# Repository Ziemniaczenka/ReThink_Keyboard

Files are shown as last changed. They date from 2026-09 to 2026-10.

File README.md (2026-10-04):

# ReThink Keyboard

Adapting older ThinkPad laptop keyboard modules into standalone keyboards using Framework Control Board.

## Hardware overview
- **Framework Control Board** - nRF54LM20A, Bluetooth/dongle/USB-C connection, nPM1300 power management IC.
- **ReThink Adapter Board** - bridge between Control Board and ThinkPad keyboards.
- **3D Printed case** - housing for components, different for each keyboard type.
- **ThinkPad keyboard modules** - 6 and 7row, classic and chiclet, with or without backlight, with integrated Pointing Stick (nub) and mouse keys. Full list TBD.
- **ZMK Firmware** - based on Zephyr RTOS, provides customizability. Each keyboard type will be different shield.

> Note: This is preliminary information. Everything is subject to change and more information will follow.

## Reference pinouts

- [Framework Control Board FFC connectors](docs/pinouts/framework_ffc.md)
- [Mezzanine Connector (e.g. T60/T420)](docs/pinouts/mezzanine.md)
- [FFC1 (e.g. L420)](docs/pinouts/ffc1.md)
- [FFC2 (e.g. T480/T580/L14)](docs/pinouts/ffc2.md)

## Mechanical CAD
  
- TBD

## ReThink Adapter

   Adapter board connects to Control Board using FFC cables, has a bunch of connectors for different generations of ThinkPad keyboard, boost converters (for pointing stick, backlight) and I2C IO expander (required to keep all keyboard buttons and diodes functional).

   - [Schematic (WiP)](circuit/ReThink_adapter.pdf)
   - [BOM (WiP)](circuit/ReThink_adapter/ReThink_adapter.csv)

## Battery

- Picoblade 3-pin with NTC thermistor.
- TBD

## Firmware and Bootloader

- ZMK Configuration will be based on GitHub in separate repository (TBD)

## Compatibility Table

- TBD

## License

ReThink keyboard by Ziemniaczenka is licensed under CC BY-SA 4.0.
To view a copy of this license, visit https://creativecommons.org/licenses/by-sa/4.0/

Component 3D models located under `circuit/libraries/3dmodels/` are the intellectual property of their respective manufacturers and are provided for reference/visualization purposes only. They are not covered by the above license; all rights remain with their original owners.

## Disclaimers
> Framework Control Board was provided pre-release by Framework Computer Inc. through Control Board Developer Program.

> ThinkPad and TrackPoint are registered trademarks of Lenovo. ReThink is an independent open-source project and is not affiliated with, endorsed by, or certified by Lenovo Group Limited.

## References
1. https://github.com/FrameworkComputer/Framework-Wireless-Touchpad-Keyboard
2. https://github.com/badjeff/kb_zmk_ps2_mouse_trackpoint_driver
3. https://github.com/rampadc/zmk-thinkpad
4. https://github.com/delingren/thinkpad_keyboards

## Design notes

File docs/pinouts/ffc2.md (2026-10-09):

# FFC 2 connector

Modern 6-row keyboard\
Dual keyed FFC connectors:
- 36-pin (40-pin with numpad) P0.5mm keyed for Matrix, LEDs, Navigation Buttons
- 12-pin P1.0mm keyed for Pointing Stick and Backlight

## Compatible connectors

1. 36-pin
   - pitch: 0.5mm
   - key: **notched**
   - side: bottom
   - lock: yes?
   - Compatible MPN:
     - HIGHS_FC5AF361-1151H (T470)
     - Hirose FH34SRJ-40S-0.5SH(50) (**40pin, straight key. Skip 2 pins from each end!**)
       - [Mouser](https://www.mouser.pl/en/ProductDetail/Hirose-Connector/FH34SRJ-40S-0.5SH50?qs=iyLo5FA4poDa6AcLdJDWMw%3D%3D)
2. 40-pin
   - pitch: 0.5mm
   - key: **tabbed**
   - side: bottom
   - lock: yes?
   - Compatible MPN:
     - JAE-CON40-7-GP (T570)
     - HIGHS_FC5AF401-3181H (L14g1, L15g1, E480, E580)
     - Hirose FH52-40S-0.5SH (**direct match**)
       - [Mouser](https://www.mouser.pl/en/ProductDetail/Hirose-Connector/FH52-40S-0.5SH?qs=x%2FqqGkZFGGusKc6kcNGZEQ%3D%3D)
3. 12-pin
   - pitch: 1.0mm
   - key: **notched**
   - side: bottom
   - lock: yes?
   - Compatible MPN:
     - HIGHS_FC1AF121-1151H (T480, L14G1)
     - JAE-CON12-1-GP-U (T580)
     - JAE_FL10F012HA1R3000 (E490)
     - Omron XF3M(1)-1415-1B (**14pin, straight key. Skip 1 pin from each end, needs aligment guide! (cable width: 14mm, 14pin socket opening width: 15mm**)
       - [Mouser](https://www.mouser.pl/en/ProductDetail/Omron-Electronics/XF3M1-1415-1B?qs=0q6jlcGHEi2cMtnOEJgNDA%3D%3D)

## Compatible models (TBD)

- T470, T480, T25 (w/o power button), A475, A485 **(12pin left, 36pin right, kb right side) Mounting hole coliding with adapter board, fix!!!**
- ~~A285, L13g1, L13g2?, X280, X290, X390, X395, X13g1? **(36pin left, 12pin right, kb left side)**~~
- T570, T580, P51s, P52s (40pin left, 12pin right, kb **right** side) **(possible collision?)**
- L14g1, L14g2 (40pin left, 12pin right, kb left side) **Mounting hole coliding with adapter board, fix!!!**
- L15g1, L15g2 (40pin left, 12pin right, kb left side) **(possible collision?)**
- E480, E485, E490, E495, L380, L390, L480, L490, T480s, T490, T14g1, T14g2, P43, P43s, P14sG1, P14sG2 (40pin left, 12pin right, kb left side)
- E580, E585, E590, E595, L580, L590, T590, P52, P53, P53s, P72, P73 (40pin left, 12pin right, kb left side)
- T15g1, T15g2, P15sG1, P15sG2 (40pin left, 12pin right, kb left side)
- P15g1, P15g2, P17g1, P17g2 (40pin left, 12pin right, kb **right** side)

## Pinout (36-pin/40pin)

|  Pin  | T480 | T580/L14 | Type | Adapter Board |
| :---: | :---: | :---: | :---: | :---: |
| 1 | SENSE3 | SENSE3 | | |
| 2 | SENSE7 | SENSE7 | | |
| 3 | SENSE6 | SENSE6 | | |
| 4 | DRV14 | DRV14 | | |
| 5 | SENSE4 | SENSE4 | | |
| 6 | SENSE1 | SENSE1 | | |
| 7 | DRV0 | DRV0 | | |
| 8 | SENSE2 | SENSE2 | | |
| 9 | SENSE0 | SENSE0 | | |
|  10 | DRV4 | DRV4 | | |
|  11 | DRV2 | DRV2 | | |
|  12 | SENSE5 | SENSE5 | | |
|  13 | DRV1 | DRV1 | | |
|  14 | DRV3 | DRV3 | | |
|  15 | DRV6 | DRV6 | | |
|  16 | DRV7 | DRV7 | | |
|  17 | DRV5 | DRV5 | | |
|  18 | DRV15 | DRV15 | | |
|  19 | DRV13 | DRV13 | | |
|  20 | DRV9 | DRV9 | | |
|  21 | DRV12 | DRV12 | | |
|  22 | DRV10 | DRV10 | | |
|  23 | DRV8 | DRV8 | | |
|  24 | DRV11 | DRV11 | | |
|  25 | VCC3M | VCC3M | 0.1u to GND | |
|  26 |  LED_FNLOCK  |  LED_FNLOCK  | 100R series resistor, 0.1u to GND | |
|  27 | LED_MUTE | LED_MUTE | 100R series resistor, 0.1u to GND | |
|  28 | LED_MICMUTE  | LED_MICMUTE  | 100R series resistor, 0.1u to GND | |
|  29 | HOTKEY | HOTKEY | | |
|  30 | GND | GND | | GND |
|  31 | LED_CAPSLOCK | LED_CAPSLOCK | 100R series resistor, 0.1u to GND | |
|  32 | GND | GND | | GND |
|  33 | TP4LEFT | TP4LEFT | | |
|  34 | TP4RIGHT | TP4RIGHT | | |
|  35 |  TP4MIDDLE |  TP4MIDDLE | | |
|  36 |  **KBD_ID**  |  **DRV16** | KBD_ID NC on 01AX516, <br/> NC on non-numpad L14 etc. | |
|  37 | - | DRV17 | NC on non-numpad L14 etc. | |
|  38 | - | LED_NUMLOCK  | NC on non-numpad L14 etc, 100R series resistor | |
|  39 | - | NC | Not Connected | |
|  40 | - | NC | Not Connected | |

## Pinout (12-pin)

|  Pin  | T480 | T580 | L14 | Type | Adapter Board |
| :---: | :---: | :---: | :---: | :---: | :---: |
| **1** |  **VCC5B**  |  **VCC5B**  |  **VCC3B**  | VCC_TP, 10nF to GND  <br/> option of 3V3 and 5V, diff defaults | |
| 2 | TP4DATA | TP4DATA | TP4DATA | Pointing Stick Data, Pullup 4.7k@VCC_TP | |
| 3 |  TP4_RESET  |  TP4_RESET  |  TP4_RESET  | Pointing Stick reset, Pullup 10k@VCC_TP | |
| 4 |  TP4MIDDLE  |  TP4MIDDLE  |  TP4MIDDLE  | | |
| 5 |  TP4RIGHT |  TP4RIGHT |  TP4RIGHT | | |
| 6 | TP4LEFT | TP4LEFT | TP4LEFT | | |
| 7 | GND | GND | GND | Pointing Stick GND | |
| 8 | TP4CLK | TP4CLK | TP4CLK | Pointing Stick Clk, 4.7k@VCC_TP | |
| 9 | VCC5B | VCC5B | VCC5B | LED VCC (5V), 2x22uF to GND | |
|  10 | KBD_BL_PWM  | KBD_BL_PWM  | KBD_BL_PWM  | LED PWM, 220p to GND | |
|  11 | KBD_BL_DTCT | KBD_BL_DTCT | KBD_BL_DTCT | Backlight detection | |
|  12 | GND | GND | GND | LED GND | |

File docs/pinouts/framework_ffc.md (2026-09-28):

# Framework Control Board FFC connectors

34-pin FFC connector for data as well as 6-pin for Backlight power  

## Compatible connectors

1. 34-pin
   - pitch: 0.5mm
   - key: straight
   - side: dual?
   - lock: back
   - Compatible MPN:
     - Hirose FH34SRJ-34S-0.5SH(50)
       - [Mouser](https://www.mouser.pl/en/ProductDetail/Hirose-Connector/FH34SRJ-34S-0.5SH50?qs=iyLo5FA4poAumYnqXazWvw%3D%3D)
2. 6-pin
   - pitch: 0.5mm
   - key: straight
   - side: dual?
   - lock: back
   - Compatible MPN:
     - Hirose FH34SRJ-6S-0.5SH(50)
       - [Mouser](https://www.mouser.pl/en/ProductDetail/Hirose-Connector/FH34SRJ-6S-0.5SH50?qs=vnk2wBG9e15jF3vv7p0sbw%3D%3D)

## Pinout (34-pin)

| Pin (CB) |  nRF  | Control Board | Type | Adapter Board | Pin (AB) |
| :---: | :---: | :---: | :---: | :---: | :---: |
| 1 | P0.00 | KSI_00_IN | | IO0 | 34 |
| 2 | P0.01 | KSI1 | | IO1 | 33 |
| 3 | P0.02 | KSI2 | | IO2 | 32 |
| 4 | P0.03 | KSI_03_IN | | IO3 | 31 |
| 5 | P0.04 | KSI4 | | IO4 | 30 |
| 6 | P0.05 | KSI5 | | IO5 | 29 |
| 7 | P0.06 | KSI6 | | IO6 | 28 |
| 8 | P0.07 | KSI7 | | IO7 | 27 |
| 9 | P1.00 | KSO0 | | IO8 | 26 |
| 10 | P1.01 | KSO1 | | IO9 | 25 |
| 11 | P1.18 | KSO_02_IN | | IO10 | 24 |
| 12 | P1.19 | KSO3 | | IO11 | 23 |
| 13 | P1.04 | KSO4 | | IO12 | 22 |
| 14 | P1.05 | KSO5 | | IO13 | 21 |
| 15 | P1.06 | KSO6 | | IO14 | 20 |
| 16 | P1.07 | KSO7 | | IO15 | 19 |
| 17 | P1.08 | KSO8 | | IO16 | 18 |
| 18 | P1.09 | KSO9 | | IO17 | 17 |
| 19 | P1.10 | KSO10 | | IO18 | 16 |
| 20 | P1.11 | KSO11 | | IO19 | 15 |
| 21 | P1.12 | KSO12 | | IO20 | 14 |
| 22 | P1.13 | KSO13 | | IO21 | 13 |
| 23 | P1.14 | KSO14 | | IO22 | 12 |
| 24 | P1.15 | KSO15 | | IO23 | 11 |
| 25 | P1.16 | KSO16 | | IO24 | 10 |
| 26 | P1.17 | KSO17 | | IO25 | 9 |
| 27 | - | CAPS_P | VLED_3.3V (always on) | LED_3V3 | 8 |
| 28 | P3.07 | CAPS_N | to ground through 330R and CAP_LED MOSFET | CAPS_N | 7 |
| 29 | - | NC | Not Connected | NC | 6 |
| 30 | P3.08 |  TP_I2C_SDA | | I2C_SDA | 5 |
| 31 | P3.04 |  TP_I2C_CLK | | I2C_CLK | 4 |
| 32 | - |  TP_VDD_3.3V  | switchable by TP_Power_Control | TP_3V3 | 3 |
| 33 | P3.06 | TP_INT | | IO26 | 2 |
| 34 | - | TP_GND | To GND through R8 0R | GND | 1 |

## Pinout (6-pin)

| Pin (CB) | Control Board | Type | Adapter Board | Pin (AB) |
| :---: | :---: | :---: | :---: | :---: |
| 1 | VLED_BL | | VIN | 6 |
| 2 | VLED_BL | | VIN | 5 |
| 3 | NC | Not Connected | | 4 |
| 4 | NC | Not Connected | | 3 |
| 5 | GND | | GND | 2 |
| 6 | GND | | GND | 1 |

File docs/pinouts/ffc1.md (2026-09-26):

# FFC 1 connector

Classic 6-row keyboard
Dual FFC connectors (30-pin P1.0mm for matrix, 8-pin P1.0mm for Pointing Stick)

## Compatible connectors

1. 30-pin
   - pitch: 1.0mm
   - key: straight
   - side: **top** (based on planed bends for adapter placement, not on laptop placement)
   - lock: yes?
   - Compatible MPN:
     - 85208-3007N-01???
     - Omron XF3M(1)-3015-1B
       - [Mouser](https://www.mouser.pl/en/ProductDetail/Omron-Electronics/XF3M1-3015-1B?qs=1He0yLMpldDsC1Cgk53qLQ%3D%3D)
2. 8-pin
   - pitch: 1.0mm
   - key: straight
   - side: **bottom**
   - lock: yes?
   - Compatible MPN:
     - Omron XF3M(1)-0815-1B
       - [Mouser](https://www.mouser.pl/en/ProductDetail/Omron-Electronics/XF3M1-0815-1B?qs=q%2FTJjBi8OU92LX9jQs7B8Q%3D%3D)

## Compatible models (TBD)

- L410 L412 L420 L421 L510 L512 L520 SL300 SL410 SL510
- X120???

## Pinout (30-pin)

|  Pin  |  L420  | Type | Adapter Board |
| :---: | :----: | :---: | :---: |
| 1 | NC | Not Connected | |
| 2 | NC | Not Connected | |
| 3 | RIGHT  | Navigation Button | |
| 4 | MIDDLE | Navigation Button | |
| 5 |  LEFT  | Navigation Button | |
| 6 |  GND | | GND |
| 7 |  MY15  | | |
| 8 |  MY10  | | |
| 9 |  MY11  | | |
|  10 |  MY14  | | |
|  11 |  MY13  | | |
|  12 |  MY12  | | |
|  13 |  MY3 | | |
|  14 |  MY6 | | |
|  15 |  MY8 | | |
|  16 |  MY7 | | |
|  17 |  MY4 | | |
|  18 |  MY2 | | |
|  19 |  MX0 | | |
|  20 |  MY1 | | |
|  21 |  MY5 | | |
|  22 |  MX3 | | |
|  23 |  MX2 | | |
|  24 |  MY0 | | |
|  25 |  MX5 | | |
|  26 |  MX4 | | |
|  27 |  MY9 | | |
|  28 |  MX6 | | |
|  29 |  MX7 | | |
|  30 |  MX1 | | |

## Pinout (8-pin)
|  Pin  | L420 | Type  | Adapter Board |
| :---: | :---: | :---: | :---: |
| 1 |  TRACK_POINT_DAT  | | |
| 2 | TRACK_POINT_RESET | | |
| 3 | MIDDLE | | |
| 4 | RIGHT | | |
| 5 | LEFT | | |
| 6 |  TRACK_POINT_CLK  | | |
| 7 | GND | | |
| 8 | 5V | | |

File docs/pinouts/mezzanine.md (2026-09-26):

# Mezzanine connector

Classic 7-row keyboard (2 types) and old chiclet

## Compatible connectors
1. Mezzanine
   - pin count: 2x20pin 
   - pitch: 0.5mm
   - Compatible MPN:
     - JAE AA01B-S040VA1 (original, hard to find)
       - [Quest Components](https://www.questcomp.com/part/4/aa01b-s040va1-r3000/434153986)
     - Molex 543630489 (WM6787CT-ND) (alternative, no locating feature, easy to break and posibility of misaligment)
       - [TTI](https://www.tti.com/content/ttiinc/en/apps/part-detail.html?partsNumber=543630489,&mfgShortname=MOL)
       - [DigiKey](https://www.digikey.pl/en/products/detail/molex/0543630489/3044861)
     - maybe 4-5353512-0???

## Compatible models (TBD)
- T60, T61, T400, R60, R61, R400, R500, W500, W700 (w/o numpad)  (classic type 1, narrow navigation keys, gap between kb and navigation keys)
- X60?, X60S?, X61?, X61S? (gap filled between kb and navigation keys)
- X200?, X210?, X300? (colorful narrow navigation keys, gap filled between kb and navigation keys)
- T410, T420, T510, T520, W510, W520, X220 (classic type 2, wide navigation keys)
- T430, T530, W530, X230 (chiclet with top bezel, optional backlight)
## Pinout

Slight differences between generations

|  Pin | T60 | T420 | T430 | Type | AdapterBoard |
| :----: | :---: | :---: | :---: | :---: | :---: |
| 1 | HOTKEY | HOTKEY | HOTKEY | Fn key (to GND) | EXP0 |
| 2 | DRV4 | DRV4 | DRV4 | | |
| 3 | SENSE5 | SENSE5 | SENSE5 | | |
| 4 | DRV5 | DRV5 | DRV5 | | |
| 5 | SENSE0 | SENSE0 | SENSE0 | | |
| 6 | DRV8 | DRV8 | DRV8 | | |
| 7 | SENSE3 | SENSE3 | SENSE3 | | |
| 8 | DRV6 | DRV6 | DRV6 | | |
| 9 | SENSE2 | SENSE2 | SENSE2 | | |
| 10 | DRV3 | DRV3 | DRV3 | | |
| 11 | SENSE4 | SENSE4 | SENSE4 | | |
| 12 | DRV7 | DRV7 | DRV7 | | |
| 13 | SENSE1 | SENSE1 | SENSE1 | | |
| 14 | DRV2 | DRV2 | DRV2 | | |
| 15 | SENSE6 | SENSE6 | SENSE6 | | |
| 16 | DRV10 | DRV10 | DRV10 | | |
| 17 | SENSE7 | SENSE7 | SENSE7 | | |
| 18 | DRV1 | DRV1 | DRV1 | | |
| 19 | PWRSWITCH  | PWRSWITCH | PWRSWITCH | Power button (to GND) | |
| 20 | DRV9 | DRV9 | DRV9 | | |
| **21** | **NC** | **LEDCPSLOCK** | **KBD_BL_DTCT** | 560R series resistor | |
| 22 | DRV0 | DRV0 | DRV0 | | |
| **23** | **NC** | **LEDPWR** | **LEDPWR** | 220R series resistor | |
| 24 | DRV11 | DRV11 | DRV11 | | |
| **25** | **KBDID0** | **KBDID0** | **KBD_BL_PWM**  | 220p C0G to GND | PWM |
| 26 | DRV14 | DRV14 | DRV14 | | |
| **27** | **KBDID1** | **KBDID1** | **GND** | | ? |
| 28 | DRV12 | DRV12 | DRV12 | | |
| **29** | **KBDID2** | **KBDID2** | **VCC5B** | 2x22uF to GND | |
| 30 | DRV15 | DRV15 | DRV15 | | |
| 31 | GND | GND | GND | | GND |
| 32 | DRV13 | DRV13 | DRV13 | | |
| **33** | **NC** |  **LED_MUTE**  |  **LED_MUTE** | 3.9k series resistor | |
| 34 | GND | GND | GND | HOTKEY/PWRSWITCH GND | GND |
| **35** | **NC** | **VCC3M** | **VCC3M** | | |
| **36** |  **GND** | **LEDMICMUTE** | **LEDMICMUTE**  | 3.9k series resistor | |
| 37 |  TP4DATA | TP4DATA | TP4DATA | TrackPoint Data line, pullup 4.7k@5V  | |
| 38 | VCC5B | VCC5B | VCC5B | TrackPoint Power 5V, 10nF decoupling  | |
| 39 | TP4CLK | TP4CLK | TP4CLK | TrackPoint Clock line, pullup 4.7k@5V | |
| 40 | TP4_RESET  | TP4_RESET | TP4_RESET | TrackPoint Reset line, pullup 10k@5V  | |

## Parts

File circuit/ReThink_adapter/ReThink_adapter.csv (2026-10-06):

Reference | Qty | Value | Voltage | Dielectric | Footprint | MPN | DNP | Exclude from BOM | Alt_MPN | RoHS | Mouser_PN | DigiKey_PN | Distributor link | Alt_link | Tolerance | Power | Exclude from Board | Exclude from Simulation | Exclude from Position Files | Datasheet
C1,C2,C6,C7,C15,C17,C18,C23 | 8 | 0.1u | 16 | X7R | Capacitor_SMD:C_0402_1005Metric | GRM155R71H104KE14D |  |  |  | Compliant | 81-GRM155R71H104KE4D | 490-10700-1-ND | https://www.mouser.pl/en/ProductDetail/Murata-Electronics/GRM155R71H104KE14D?qs=2UZY3JfgLCy9gG9icKV9Yg%3D%3D | https://www.digikey.pl/en/products/detail/murata-electronics/GRM155R71H104KE14D/4906220 |  |  |  |  | ${EXCLUDE_FROM_POS_FILES}
C3,C4,C9,C10,C11 | 5 | 10u | 16 | X5R | Capacitor_SMD:C_0603_1608Metric | GRM188R61E106MA73J |  |  |  | Compliant | 81-GRM188R61E106MA3J | 1276-1869-1-ND | https://www.mouser.pl/en/ProductDetail/Murata-Electronics/GRM188R61E106MA73J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 | https://www.digikey.pl/en/products/detail/samsung-electro-mechanics/CL10A106MA8NRNC/3887527 |  |  |  |  | ${EXCLUDE_FROM_POS_FILES}
C5 | 1 | 1u | 10 | X7R | Capacitor_SMD:C_0603_1608Metric | MLAST168SB7105KTNA01 |  |  |  | Compliant | 963-MLAST168SB7105KT | 587-MLAST168SB7105KTNA01CT-ND | https://www.mouser.pl/en/ProductDetail/TAIYO-YUDEN/MLAST168SB7105KTNA01?qs=tlsG%2FOw5FFhx%252B2apRN1HpA%3D%3D | https://www.digikey.pl/en/products/detail/taiyo-yuden/MLAST168SB7105KTNA01/16665343 |  |  |  |  | ${EXCLUDE_FROM_POS_FILES}
C8 | 1 | 100p | 25 | C0G | Capacitor_SMD:C_0402_1005Metric | GRM1555C2A101GA01D |  |  |  | Compliant | 81-GRM1555C2A101GA1D | 490-GRM1555C2A101GA01DCT-ND | https://www.mouser.pl/en/ProductDetail/Murata-Electronics/GRM1555C2A101GA01D?qs=hNud%2FORuBR2mSE1RPo5yOg%3D%3D | https://www.digikey.pl/en/products/detail/murata-electronics/GRM1555C2A101GA01D/17843758 |  |  |  |  | ${EXCLUDE_FROM_POS_FILES}
C12,C13,C19,C20 | 4 | 22u | 16 | X5R | Capacitor_SMD:C_0805_2012Metric | GRM219R61C226ME15K |  |  |  | Compliant | 81-GRM219R61C226ME1K | 490-GRM219R61C226ME15KCT-ND | https://www.mouser.pl/en/ProductDetail/Murata-Electronics/GRM219R61C226ME15K?qs=F5EMLAvA7IDHNVqFg3MF1Q%3D%3D | https://www.digikey.pl/en/products/detail/murata-electronics/GRM219R61C226ME15K/11618740 |  |  |  |  | ${EXCLUDE_FROM_POS_FILES}
C14 | 1 | 10n | 25 | X7R | Capacitor_SMD:C_0402_1005Metric | CL05B103KB5NNNC |  |  |  | Compliant | 187-CL05B103KB5NNNC | 1276-1028-1-ND | https://www.mouser.pl/en/ProductDetail/Samsung-Electro-Mechanics/CL05B103KB5NNNC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 | https://www.digikey.pl/en/products/detail/samsung-electro-mechanics/CL05B103KB5NNNC/3886686 |  |  |  |  | ${EXCLUDE_FROM_POS_FILES}
C16,C21 | 2 | 220p | 25 | C0G | Capacitor_SMD:C_0402_1005Metric | C0402C221J2GACTU | DNP |  |  | Compliant | 80-C0402C221J2GACTU | 399-C0402C221J2GACTUCT-ND | https://www.mouser.pl/en/ProductDetail/KEMET/C0402C221J2GACTU?qs=WyjlAZoYn52wza2weOA0ZQ%3D%3D | https://www.digikey.pl/en/products/detail/kemet/C0402C221J2GACTU/18195347 |  |  |  |  | ${EXCLUDE_FROM_POS_FILES}
C22 | 1 | 220p | 25 | C0G | Capacitor_SMD:C_0402_1005Metric | C0402C221J2GACTU |  |  |  | Compliant | 80-C0402C221J2GACTU | 399-C0402C221J2GACTUCT-ND | https://www.mouser.pl/en/ProductDetail/KEMET/C0402C221J2GACTU?qs=WyjlAZoYn52wza2weOA0ZQ%3D%3D | https://www.digikey.pl/en/products/detail/kemet/C0402C221J2GACTU/18195347 |  |  |  |  | ${EXCLUDE_FROM_POS_FILES}
J1 | 1 | FH34SRJ-34S-0.5SH(50) |  |  | ReThink_footprints:FH34SRJ-34S-0.5SH(50) | FH34SRJ-34S-0.5SH(50) |  |  |  | Compliant | 798-FH34SRJ34S05SH50 | 26-FH34SRJ-34S-0.5SH(50)CT-ND | https://www.mouser.pl/en/ProductDetail/Hirose-Connector/FH34SRJ-34S-0.5SH50?qs=iyLo5FA4poAumYnqXazWvw%3D%3D | https://www.digikey.pl/en/products/detail/hirose-electric-co-ltd/FH34SRJ-34S-0-5SH-50/5132530 |  |  |  |  | ${EXCLUDE_FROM_POS_FILES}
J2 | 1 | FH34SRJ-6S-0.5SH(50) |  |  | ReThink_footprints:FH34SRJ-6S-0.5SH(50) | FH34SRJ-6S-0.5SH(50) |  |  |  | Compliant | 798-FH34SRJ6S05SH50 | H125773CT-ND | https://www.mouser.pl/en/ProductDetail/Hirose-Connector/FH34SRJ-6S-0.5SH50?qs=vnk2wBG9e15jF3vv7p0sbw%3D%3D | https://www.digikey.pl/en/products/detail/hirose-electric-co-ltd/FH34SRJ-6S-0-5SH-50/4283771 |  |  |  |  | ${EXCLUDE_FROM_POS_FILES}
J3 | 1 | Mezzanine |  |  | ReThink_footprints:Mezzanine_combo | AA01B-S040VA1 |  |  | 0543630489 | UNKNOWN |  | WM6787CT-ND | https://www.questcomp.com/part/4/aa01b-s040va1-r3000/434153986 | https://www.digikey.pl/en/products/detail/molex/0543630489/3044861 |  |  |  |  | ${EXCLUDE_FROM_POS_FILES} | https://www.molex.com/en-us/products/part-detail-pdf/543630489?display=pdf
J4 | 1 | XF3M(1)-3015-1B |  |  | ReThink_footprints:XF3M(1)-3015-1B | XF3M(1)-3015-1B |  |  |  | Compliant | 653-XF3M1-3015-1B | OR1179CT-ND | https://www.mouser.pl/en/ProductDetail/Omron-Electronics/XF3M1-3015-1B?qs=1He0yLMpldDsC1Cgk53qLQ%3D%3D | https://www.digikey.pl/en/products/detail/aratas-formerly-omron-components/XF3M-1-3015-1B/4331813 |  |  |  |  | ${EXCLUDE_FROM_POS_FILES}
J5 | 1 | XF3M(1)-0815-1B |  |  | ReThink_footprints:XF3M(1)-0815-1B | XF3M(1)-0815-1B |  |  |  | Compliant | 653-XF3M108151B | OR1222CT-ND | https://www.mouser.pl/en/ProductDetail/Omron-Electronics/XF3M1-0815-1B?qs=q%2FTJjBi8OU92LX9jQs7B8Q%3D%3D | https://www.digikey.pl/en/products/detail/aratas-formerly-omron-components/XF3M-1-0815-1B/4975954 |  |  |  |  | ${EXCLUDE_FROM_POS_FILES}
J6 | 1 | FH34SRJ-40S-0.5SH(50) |  |  | ReThink_footprints:FH34SRJ-40S-0.5SH(50) | FH34SRJ-40S-0.5SH(50) |  |  |  | Compliant | 798-FH34SRJ40S05SH50 | H125755CT-ND | https://www.mouser.pl/en/ProductDetail/Hirose-Connector/FH34SRJ-40S-0.5SH50?qs=iyLo5FA4poDa6AcLdJDWMw%3D%3D | https://www.digikey.pl/en/products/detail/hirose-electric-co-ltd/FH34SRJ-40S-0-5SH-50/5132532 |  |  |  |  | ${EXCLUDE_FROM_POS_FILES}
J7 | 1 | FH52-40S-0.5SH |  |  | ReThink_footprints:FH52-40S-0.5SH | FH52-40S-0.5SH |  |  |  | Compliant | 798-FH5240S0.5SH | HFZ040CT-ND | https://www.mouser.pl/en/ProductDetail/Hirose-Connector/FH52-40S-0.5SH?qs=x%2FqqGkZFGGusKc6kcNGZEQ%3D%3D | https://www.digikey.pl/en/products/detail/hirose-electric-co-ltd/FH52-40S-0-5SH-99/3461668 |  |  |  |  | ${EXCLUDE_FROM_POS_FILES}
J8 | 1 | XF3M(1)-1415-1B |  |  | ReThink_footprints:XF3M(1)-1415-1B | XF3M(1)-1415-1B |  |  |  | Compliant | 653-XF3M114151B | Z5875CT-ND | https://www.mouser.pl/en/ProductDetail/Omron-Electronics/XF3M1-1415-1B?qs=0q6jlcGHEi2cMtnOEJgNDA%3D%3D | https://www.digikey.pl/en/products/detail/aratas-formerly-omron-components/XF3M-1-1415-1B/6072100 |  |  |  |  | ${EXCLUDE_FROM_POS_FILES}
L1 | 1 | 1u |  |  | ReThink_footprints:L_0806_2016Metric | IHHP0806ZHER1R0M01 |  |  |  | Compliant | 70-IHHP0806ZHR1R0M01 | 541-IHHP0806ZHER1R0M01CT-ND | https://www.mouser.pl/en/ProductDetail/Vishay-Dale/IHHP0806ZHER1R0M01?qs=tlsG%2FOw5FFg%2FJRP1dsWtCQ%3D%3D | https://www.digikey.pl/en/products/detail/vishay-dale/IHHP0806ZHER1R0M01/16583532 |  |  |  |  | ${EXCLUDE_FROM_POS_FILES}
R1,R2,R3,R4,R14,R22 | 6 | 10k |  |  | Resistor_SMD:R_0402_1005Metric | RC0402FR-0710KP |  |  |  | Compliant | 603-RC0402FR-0710KP | YAG1249CT-ND | https://www.mouser.pl/en/ProductDetail/YAGEO/RC0402FR-0710KP | https://www.digikey.pl/en/products/detail/yageo/RC0402FR-0710KP/4935264 |  |  |  |  | ${EXCLUDE_FROM_POS_FILES}
R5 | 1 | 200k |  |  | Resistor_SMD:R_0402_1005Metric | RC0402FR-07200KP |  |  |  | Compliant | 603-RC0402FR-07200KP | 13-RC0402FR-07200KPCT-ND | https://www.mouser.pl/en/ProductDetail/YAGEO/RC0402FR-07200KP | https://www.digikey.pl/en/products/detail/yageo/RC0402FR-07200KP/17020059 |  |  |  |  | ${EXCLUDE_FROM_POS_FILES}
R6,R7,R8,R9 | 4 | 4.7k |  |  | Resistor_SMD:R_0402_1005Metric | RC0402FR-074K7P |  |  |  | Compliant | 603-RC0402FR-074K7P | YAG1272CT-ND | https://www.mouser.pl/en/ProductDetail/YAGEO/RC0402FR-074K7P | https://www.digikey.pl/en/products/detail/yageo/RC0402FR-074K7P/4935287 |  |  |  |  | ${EXCLUDE_FROM_POS_FILES}
R10 | 1 | 2.2k |  |  | Resistor_SMD:R_0402_1005Metric | RC0402FR-072K2P |  |  |  | Compliant | 603-RC0402FR-072K2P | YAG1260CT-ND | https://www.mouser.pl/en/ProductDetail/YAGEO/RC0402FR-072K2P | https://www.digikey.pl/en/products/detail/yageo/RC0402FR-072K2P/4935275 |  |  |  |  | ${EXCLUDE_FROM_POS_FILES}
R11 | 1 | 560 |  |  | Resistor_SMD:R_0402_1005Metric | RC0402FR-07560RL |  |  |  | Exemption | 603-RC0402FR-07560RL | 311-560LRCT-ND | https://www.mouser.pl/en/ProductDetail/YAGEO/RC0402FR-07560RL?qs=Is6ZsIPfHkaar5c8drXNXg%3D%3D | https://www.digikey.pl/en/products/detail/yageo/RC0402FR-07560RL/726638 |  |  |  |  | ${EXCLUDE_FROM_POS_FILES}
R12 | 1 | 220 |  |  | Resistor_SMD:R_0402_1005Metric | RC0402FR-07220RP |  |  |  | Compliant | 603-RC0402FR-07220RP | 13-RC0402FR-07220RPCT-ND | https://www.mouser.pl/en/ProductDetail/YAGEO/RC0402FR-07220RP | https://www.digikey.pl/en/products/detail/yageo/RC0402FR-07220RP/17015787 |  |  |  |  | ${EXCLUDE_FROM_POS_FILES}
R13 | 1 | 330 |  |  | Resistor_SMD:R_0402_1005Metric | RC0402FR-07330RL |  |  |  | Exemption | 603-RC0402FR-07330RL | 311-330LRCT-ND | https://www.mouser.pl/en/ProductDetail/YAGEO/RC0402FR-07330RL?qs=V1yeUXFNrkngRWHRQxns%2Fg%3D%3D | https://www.digikey.pl/en/products/detail/yageo/RC0402FR-07330RL/726594 |  |  |  |  | ${EXCLUDE_FROM_POS_FILES}
R15,R16 | 2 | 3.9k |  |  | Resistor_SMD:R_0402_1005Metric | RC0402FR-073K9L |  |  |  | Exemption | 603-RC0402FR-073K9L | 311-3.90KLRCT-ND | https://www.mouser.pl/en/ProductDetail/YAGEO/RC0402FR-073K9L?qs=YUgVZYePFqAZ%2F08ApUOsXg%3D%3D | https://www.digikey.pl/en/products/detail/yageo/RC0402FR-073K9L/726584 |  |  |  |  | ${EXCLUDE_FROM_POS_FILES}
R17,R18,R19,R20,R21 | 5 | 100 |  |  | Resistor_SMD:R_0402_1005Metric | RC0402FR-07100RP |  |  |  | Compliant | 603-RC0402FR-07100RP | YAG1248CT-ND | https://www.mouser.pl/en/ProductDetail/YAGEO/RC0402FR-07100RP | https://www.digikey.pl/en/products/detail/yageo/RC0402FR-07100RP/4935263 |  |  |  |  | ${EXCLUDE_FROM_POS_FILES}
R23 | 1 | 10k |  |  | Resistor_SMD:R_0402_1005Metric | RC0402FR-0710KP | DNP |  |  | Compliant | 603-RC0402FR-0710KP | YAG1249CT-ND | https://www.mouser.pl/en/ProductDetail/YAGEO/RC0402FR-0710KP | https://www.digikey.pl/en/products/detail/yageo/RC0402FR-0710KP/4935264 |  |  |  |  | ${EXCLUDE_FROM_POS_FILES}
R24 | 1 | 100k |  |  | Resistor_SMD:R_0402_1005Metric | RC0402FR-07100KP |  |  |  | Compliant | 603-RC0402FR-07100KP | 13-RC0402FR-07100KPCT-ND | https://www.mouser.pl/en/ProductDetail/YAGEO/RC0402FR-07100KP?qs=qpJ%252B%252B%252Bdg6p0q%252ByEBEtQROQ%3D%3D | https://www.digikey.pl/en/products/detail/yageo/RC0402FR-07100KP/12698883 |  |  |  |  | ${EXCLUDE_FROM_POS_FILES}
U1 | 1 | PCAL6416AHF |  |  | Package_DFN_QFN:HVQFN-24-1EP_4x4mm_P0.5mm_EP2.1x2.1mm | PCAL6416AHF,128 |  |  |  | Compliant | 771-PCAL6416AHF,128 | 568-9946-1-ND | https://www.mouser.pl/en/ProductDetail/NXP-Semiconductors/PCAL6416AHF128?qs=Slg7U9gp9IPc62MTs1NATQ%3D%3D | https://www.digikey.pl/en/products/detail/nxp-usa-inc/PCAL6416AHF-128/3598043 |  |  |  |  | ${EXCLUDE_FROM_POS_FILES} | https://www.nxp.com/docs/en/data-sheet/PCAL6416A.pdf
U2 | 1 | LM2775DSG |  |  | Package_SON:Texas_DSG0008A_WSON-8-1EP_2x2mm_P0.5mm_EP0.9x1.6mm | LM2775DSGT |  |  |  | Compliant | 595-LM2775DSGT | 296-42149-1-ND | https://www.mouser.pl/en/ProductDetail/Texas-Instruments/LM2775DSGT?qs=GURawfaeGuC8OeiXDzqVsg%3D%3D | https://www.digikey.pl/en/products/detail/texas-instruments/LM2775DSGT/5287374 |  |  |  |  | ${EXCLUDE_FROM_POS_FILES} | https://www.ti.com/lit/gpn/lm2775
U3 | 1 | PCA9306 |  |  | Package_SO:VSSOP-8_2.3x2mm_P0.5mm | PCA9306DCUR |  |  |  | Compliant | 595-PCA9306DCUR | 296-17988-1-ND | https://www.mouser.pl/en/ProductDetail/Texas-Instruments/PCA9306DCUR?qs=wgAEGBTxy7nQr5PRxNBUNA%3D%3D | https://www.digikey.pl/en/products/detail/texas-instruments/PCA9306DCUR/768359 |  |  |  |  | ${EXCLUDE_FROM_POS_FILES} | http://www.ti.com/lit/ds/symlink/pca9306.pdf
U4 | 1 | TPS610333DRLR |  |  | Package_TO_SOT_SMD:SOT-583-8 | TPS610333DRLR |  |  |  | Compliant | 595-TPS610333DRLR | 296-TPS610333DRLRCT-ND | https://www.mouser.pl/en/ProductDetail/Texas-Instruments/TPS610333DRLR?qs=HoCaDK9Nz5dzV%252Bptf%2FLKkg%3D%3D | https://www.digikey.pl/en/products/detail/texas-instruments/TPS610333DRLR/22106777 |  |  |  |  | ${EXCLUDE_FROM_POS_FILES} | https://www.ti.com/lit/gpn/tps610333

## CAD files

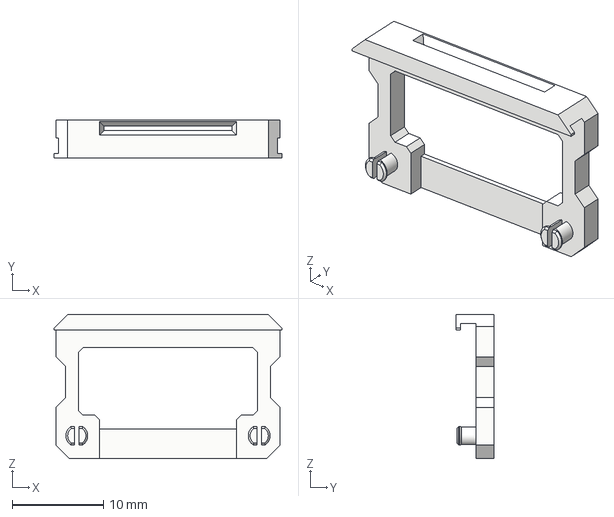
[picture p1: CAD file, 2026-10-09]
3D-models/ReThink_adapter/connector_guideV1.step
25.0 x 4.20 x 15.8 mm

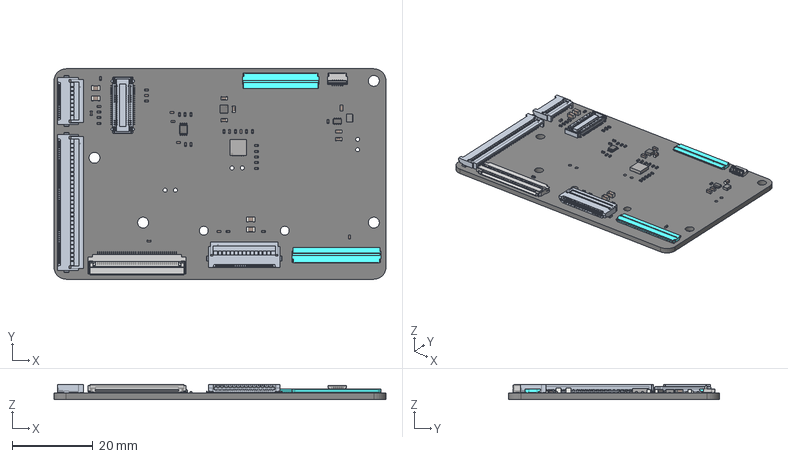
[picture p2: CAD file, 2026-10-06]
circuit/ReThink_adapter/ReThink_adapter.step
82.0 x 52.0 x 3.60 mm
C_0402_1005Metric x 11
R_0402_1005Metric x 23
C_0805_2012Metric x 4
WSON_8_1EP_2x2mm_P05mm_EP09x16mm
C_0603_1608Metric x 6
FH34SRJ-6S_ACTUATOROPEN.PRT
XF3M_1__0815_1B
WFH-2600425
HVQFN_24_1EP_4x4mm_P05mm_EP21x21mm
L_0806_2016Metric v1
XF3M_1__3015_1B
XF3M_1__1415_1B
FH34SRJ-34S-0.5SH
FH52-40S-0.5SH
VSSOP-8_2.3x2mm_P0.5mm
SOT-583-8
ReThink_adapter_PCB

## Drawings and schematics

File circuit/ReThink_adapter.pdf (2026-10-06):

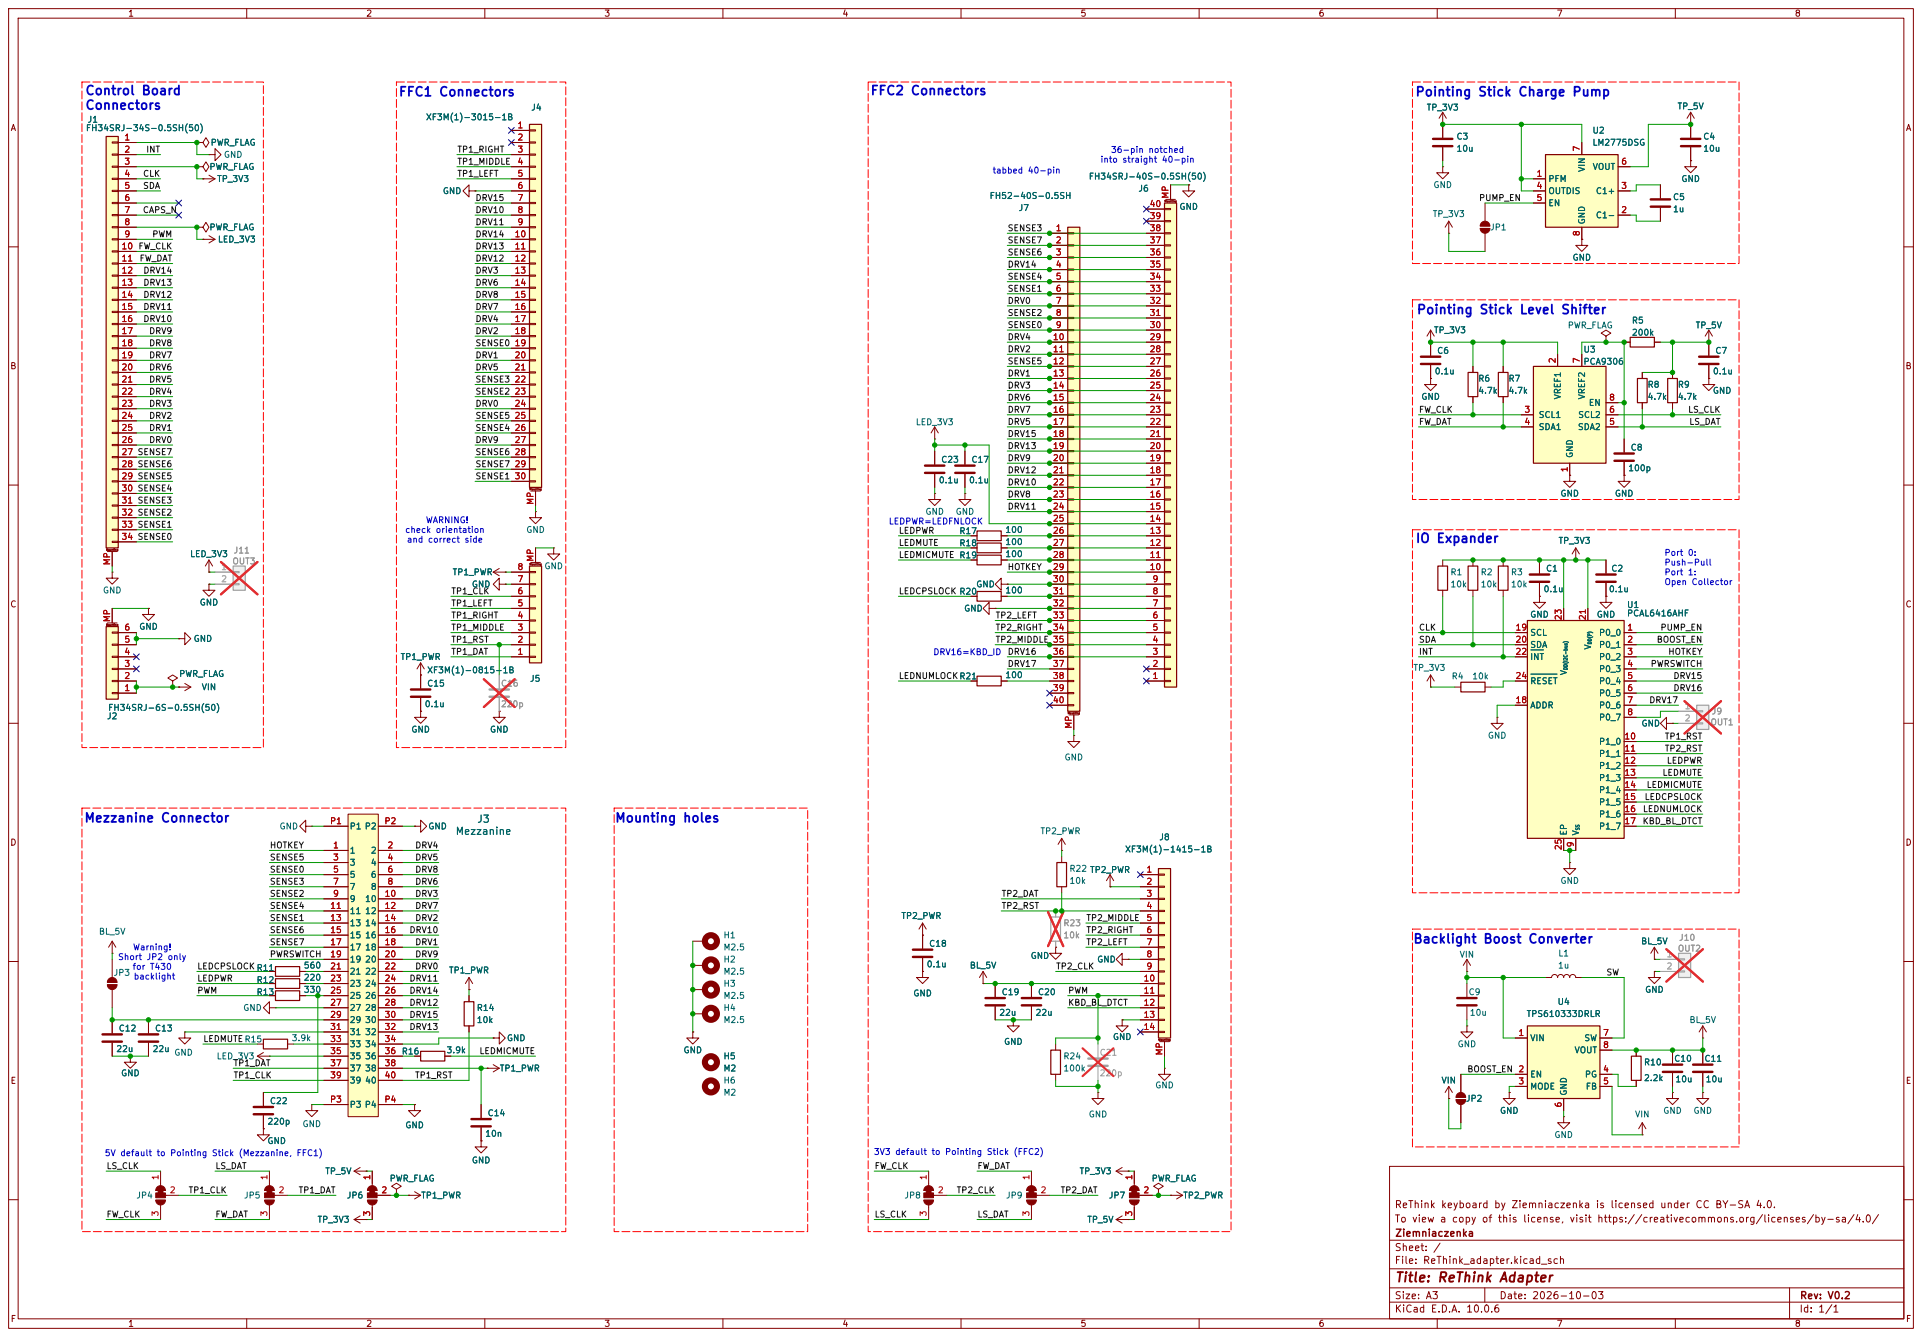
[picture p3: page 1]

Pointing Stick Charge Pump
LM2775DSG

ReThink keyboard by Ziemniaczenka is licensed under CC BY-SA 4.0. GND

To view a copy of this license, visit https://creativecommons.org/licenses/by-sa/4.0/
Ziemniaczenka
Sheet: /
File: ReThink_adapter.kicad_sch
Title: ReThink Adapter

Size: A3 | Rev: V0.2
KiCad E.D.A. 10.0.6 | Id: 1/1

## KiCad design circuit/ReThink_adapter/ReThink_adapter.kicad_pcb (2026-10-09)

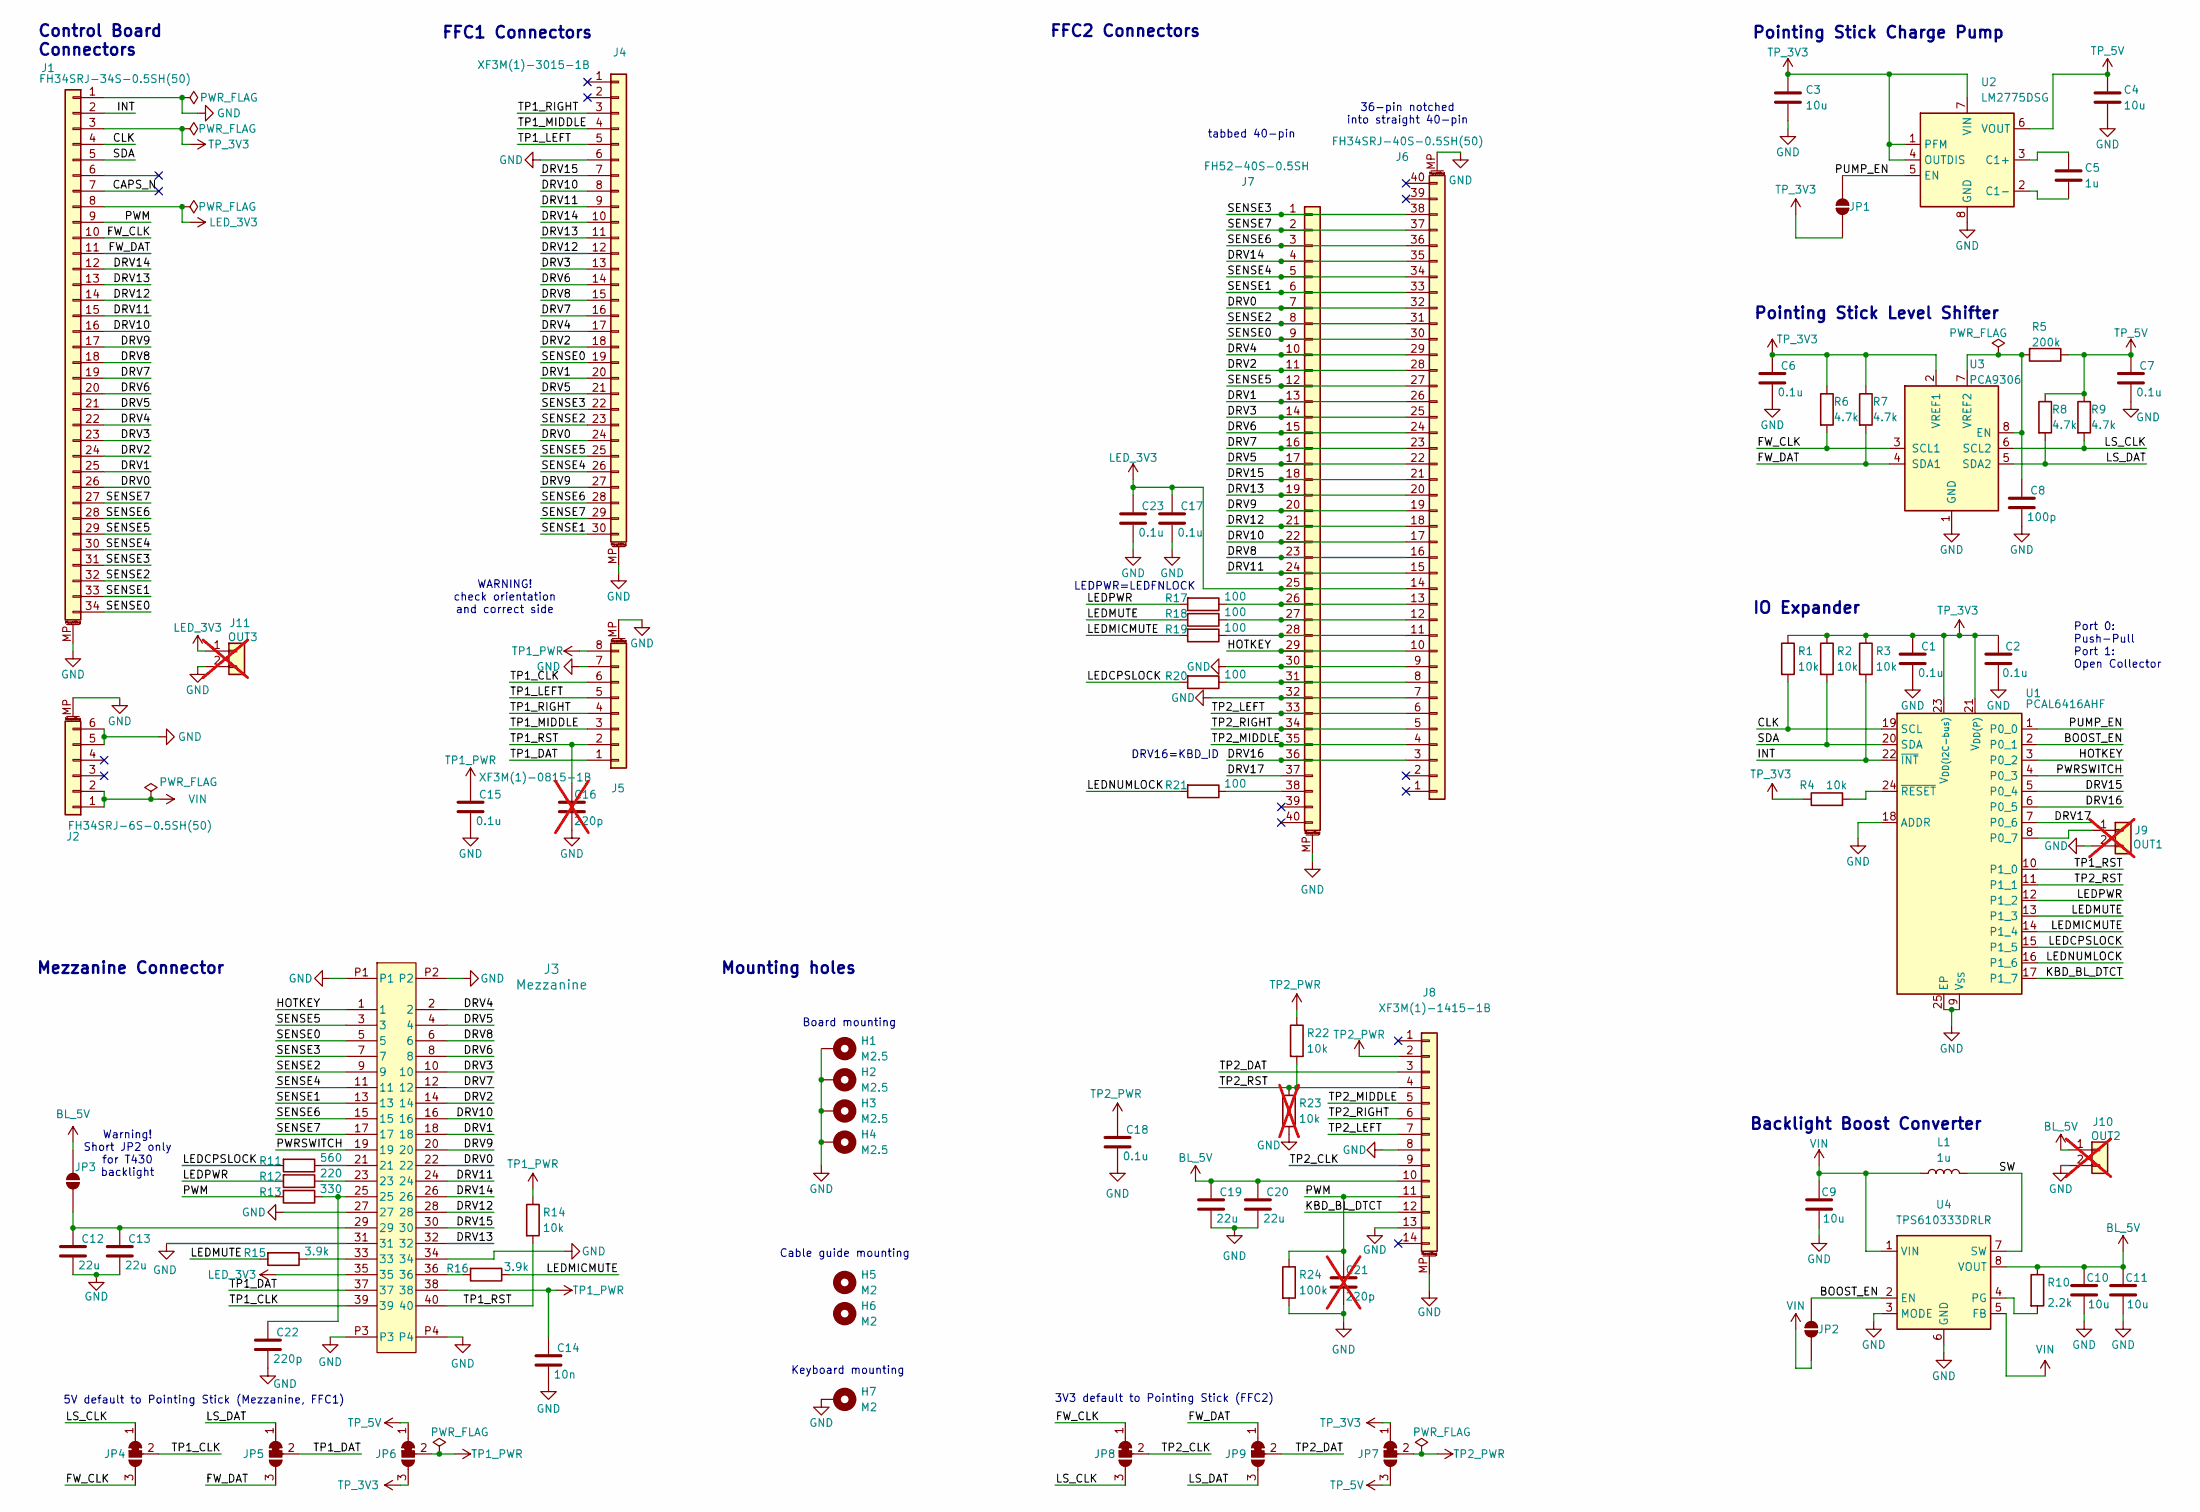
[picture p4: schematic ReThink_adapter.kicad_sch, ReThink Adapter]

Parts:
C1, C2, C6, C7, C15, C17, C18, C23: 0.1u; C_0402_1005Metric; Voltage 16; MPN GRM155R71H104KE14D; DigiKey_PN 490-10700-1-ND
C3, C4, C9, C10, C11: 10u; C_0603_1608Metric; Voltage 16; MPN GRM188R61E106MA73J; DigiKey_PN 1276-1869-1-ND
C5: 1u; C_0603_1608Metric; Voltage 10; MPN MLAST168SB7105KTNA01; DigiKey_PN 587-MLAST168SB7105KTNA01CT-ND
C8: 100p; C_0402_1005Metric; Voltage 25; MPN GRM1555C2A101GA01D; DigiKey_PN 490-GRM1555C2A101GA01DCT-ND
C12, C13, C19, C20: 22u; C_0805_2012Metric; Voltage 16; MPN GRM219R61C226ME15K; DigiKey_PN 490-GRM219R61C226ME15KCT-ND
C14: 10n; C_0402_1005Metric; Voltage 25; MPN CL05B103KB5NNNC; DigiKey_PN 1276-1028-1-ND
C16, C21: 220p; C_0402_1005Metric; Voltage 25; MPN C0402C221J2GACTU; DigiKey_PN 399-C0402C221J2GACTUCT-ND; not fitted
C22: 220p; C_0402_1005Metric; Voltage 25; MPN C0402C221J2GACTU; DigiKey_PN 399-C0402C221J2GACTUCT-ND
H1, H2, H3, H4: M2.5; MountingHole_2.7mm_M2.5_DIN965_Pad
H5, H6: M2; MountingHole_2.2mm_M2_ISO14580
H7: M2; MountingHole_2.2mm_M2_ISO14580_Pad
J1: FH34SRJ-34S-0.5SH(50); MPN FH34SRJ-34S-0.5SH(50); DigiKey_PN 26-FH34SRJ-34S-0.5SH(50)CT-ND
J2: FH34SRJ-6S-0.5SH(50); MPN FH34SRJ-6S-0.5SH(50); DigiKey_PN H125773CT-ND
J3: Mezzanine; Mezzanine_combo; MPN AA01B-S040VA1; DigiKey_PN WM6787CT-ND
J4: XF3M(1)-3015-1B; MPN XF3M(1)-3015-1B; DigiKey_PN OR1179CT-ND
J5: XF3M(1)-0815-1B; MPN XF3M(1)-0815-1B; DigiKey_PN OR1222CT-ND
J6: FH34SRJ-40S-0.5SH(50); MPN FH34SRJ-40S-0.5SH(50); DigiKey_PN H125755CT-ND
J7: FH52-40S-0.5SH; MPN FH52-40S-0.5SH; DigiKey_PN HFZ040CT-ND
J8: XF3M(1)-1415-1B; MPN XF3M(1)-1415-1B; DigiKey_PN Z5875CT-ND
J9: OUT1; PinHeader_1x02_P2.54mm_Vertical; not fitted
J10: OUT2; PinHeader_1x02_P2.54mm_Vertical; not fitted
J11: OUT3; PinHeader_1x02_P2.54mm_Vertical; not fitted
JP1, JP2, JP3: SolderJumper_2_Open; SolderJumper-2_P1.3mm_Open_RoundedPad1.0x1.5mm
JP4, JP5, JP6, JP7, JP8, JP9: SolderJumper_3_Bridged12; SolderJumper-3_P1.3mm_Bridged12_RoundedPad1.0x1.5mm_NumberL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
L1: 1u; L_0806_2016Metric; MPN IHHP0806ZHER1R0M01; DigiKey_PN 541-IHHP0806ZHER1R0M01CT-ND
R1, R2, R3, R4, R14, R22: 10k; R_0402_1005Metric; MPN RC0402FR-0710KP; DigiKey_PN YAG1249CT-ND
R5: 200k; R_0402_1005Metric; MPN RC0402FR-07200KP; DigiKey_PN 13-RC0402FR-07200KPCT-ND
R6, R7, R8, R9: 4.7k; R_0402_1005Metric; MPN RC0402FR-074K7P; DigiKey_PN YAG1272CT-ND
R10: 2.2k; R_0402_1005Metric; MPN RC0402FR-072K2P; DigiKey_PN YAG1260CT-ND
R11: 560; R_0402_1005Metric; MPN RC0402FR-07560RL; DigiKey_PN 311-560LRCT-ND
R12: 220; R_0402_1005Metric; MPN RC0402FR-07220RP; DigiKey_PN 13-RC0402FR-07220RPCT-ND
R13: 330; R_0402_1005Metric; MPN RC0402FR-07330RL; DigiKey_PN 311-330LRCT-ND
R15, R16: 3.9k; R_0402_1005Metric; MPN RC0402FR-073K9L; DigiKey_PN 311-3.90KLRCT-ND
R17, R18, R19, R20, R21: 100; R_0402_1005Metric; MPN RC0402FR-07100RP; DigiKey_PN YAG1248CT-ND
R23: 10k; R_0402_1005Metric; MPN RC0402FR-0710KP; DigiKey_PN YAG1249CT-ND; not fitted
R24: 100k; R_0402_1005Metric; MPN RC0402FR-07100KP; DigiKey_PN 13-RC0402FR-07100KPCT-ND
U1: PCAL6416AHF; HVQFN-24-1EP_4x4mm_P0.5mm_EP2.1x2.1mm; MPN PCAL6416AHF,128; DigiKey_PN 568-9946-1-ND
U2: LM2775DSG; Texas_DSG0008A_WSON-8-1EP_2x2mm_P0.5mm_EP0.9x1.6mm; MPN LM2775DSGT; DigiKey_PN 296-42149-1-ND
U3: PCA9306; VSSOP-8_2.3x2mm_P0.5mm; MPN PCA9306DCUR; DigiKey_PN 296-17988-1-ND
U4: TPS610333DRLR; SOT-583-8; MPN TPS610333DRLR; DigiKey_PN 296-TPS610333DRLRCT-ND

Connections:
/BOOST_EN: JP2.2 (B), U1.2 (P0_1), U4.2 (EN)
/CAPS_N: J1.7
/CLK: J1.4, R1.2, U1.19 (SCL)
/DRV0: J1.26, J3.22, J4.24, J6.32, J7.7
/DRV1: J1.25, J3.18, J4.20, J6.26, J7.13
/DRV2: J1.24, J3.14, J4.18, J6.28, J7.11
/DRV3: J1.23, J3.10, J4.13, J6.25, J7.14
/DRV4: J1.22, J3.2, J4.17, J6.29, J7.10
/DRV5: J1.21, J3.4, J4.21, J6.22, J7.17
/DRV6: J1.20, J3.8, J4.14, J6.24, J7.15
/DRV7: J1.19, J3.12, J4.16, J6.23, J7.16
/DRV8: J1.18, J3.6, J4.15, J6.16, J7.23
/DRV9: J1.17, J3.20, J4.27, J6.19, J7.20
/DRV10: J1.16, J3.16, J4.8, J6.17, J7.22
/DRV11: J1.15, J3.24, J4.9, J6.15, J7.24
/DRV12: J1.14, J3.28, J4.12, J6.18, J7.21
/DRV13: J1.13, J3.32, J4.11, J6.20, J7.19
/DRV14: J1.12, J3.26, J4.10, J6.35, J7.4
/DRV15: J3.30, J4.7, J6.21, J7.18, U1.5 (P0_4)
/DRV16: J6.3, J7.36, U1.6 (P0_5)
/DRV17: J7.37, U1.7 (P0_6)
/FW_CLK: J1.10, JP4.3 (B), JP8.1 (A), R6.2, U3.3 (SCL1)
/FW_DAT: J1.11, JP5.3 (B), JP9.1 (A), R7.2, U3.4 (SDA1)
/HOTKEY: J3.1, J6.10, J7.29, U1.3 (P0_2)
/INT: J1.2, R3.2, U1.22 (~INT)
/KBD_BL_DTCT: J8.12, U1.17 (P1_7)
/LEDCPSLOCK: R11.2, R20.2, U1.15 (P1_5)
/LEDMICMUTE: R16.1, R19.2, U1.14 (P1_4)
/LEDMUTE: R15.2, R18.2, U1.13 (P1_3)
/LEDNUMLOCK: R21.2, U1.16 (P1_6)
/LEDPWR: R12.2, R17.2, U1.12 (P1_2)
/LS_CLK: JP4.1 (A), JP8.3 (B), R9.2, U3.6 (SCL2)
/LS_DAT: JP5.1 (A), JP9.3 (B), R8.2, U3.5 (SDA2)
/PUMP_EN: JP1.2 (B), U1.1 (P0_0), U2.5 (EN)
/PWM: C21.1, J1.9, J8.11, R13.2, R24.1
/PWRSWITCH: J3.19, U1.4 (P0_3)
/SDA: J1.5, R2.2, U1.20 (SDA)
/SENSE0: J1.34, J3.5, J4.19, J6.30, J7.9
/SENSE1: J1.33, J3.13, J4.30, J6.33, J7.6
/SENSE2: J1.32, J3.9, J4.23, J6.31, J7.8
/SENSE3: J1.31, J3.7, J4.22, J6.38, J7.1
/SENSE4: J1.30, J3.11, J4.26, J6.34, J7.5
/SENSE5: J1.29, J3.3, J4.25, J6.27, J7.12
/SENSE6: J1.28, J3.15, J4.28, J6.36, J7.3
/SENSE7: J1.27, J3.17, J4.29, J6.37, J7.2
/SW: L1.2, U4.7 (SW)
/TP1_CLK: J3.39, J5.6, JP4.2 (C)
/TP1_DAT: J3.37, J5.1, JP5.2 (C)
/TP1_LEFT: J4.5, J5.5
/TP1_MIDDLE: J4.4, J5.3
/TP1_RIGHT: J4.3, J5.4
/TP1_RST: C16.1, J3.40, J5.2, R14.2, U1.10 (P1_0)
/TP2_CLK: J8.9, JP8.2 (C)
/TP2_DAT: J8.3, JP9.2 (C)
/TP2_LEFT: J6.6, J7.33, J8.7
/TP2_MIDDLE: J6.4, J7.35, J8.5
/TP2_RIGHT: J6.5, J7.34, J8.6
/TP2_RST: J8.4, R22.2, R23.1, U1.11 (P1_1)
BL_5V: C10.1, C11.1, C19.1, C20.1, J8.10, J10.1, JP3.1 (A), R10.1, U4.8 (VOUT)
GND: C1.2, C2.2, C3.2, C4.2, C6.2, C7.2, C8.2, C9.2, C10.2, C11.2, C12.2, C13.2, C14.2, C15.2, C16.2, C17.2, C18.2, C19.2, C20.2, C21.2, C22.2, C23.2, H1.1 (1_1), H2.1 (1_1), H3.1 (1_1), H4.1 (1_1), H7.1 (1_1), J1.1, J1.MP (MountPin), J2.5, J2.6, J2.MP (MountPin), J3.27, J3.31, J3.34, J3.P1, J3.P2, J3.P3, J3.P4, J4.6, J4.MP (MountPin), J5.7, J5.MP (MountPin), J6.7, J6.9, J6.MP (MountPin), J7.30, J7.32, J7.MP (MountPin), J8.8, J8.13, J8.MP (MountPin), J9.2, J10.2, J11.2, R23.2, R24.2, U1.9 (V_{SS}), U1.18 (ADDR), U1.25 (EP), U2.8 (GND), U2.9 (GND), U3.1 (GND), U4.3 (MODE), U4.6 (GND)
LED_3V3: C17.1, C23.1, J1.8, J3.35, J6.14, J7.25, J11.1
unnamed: C22.1, J3.25, R13.1
unnamed: J3.21, R11.1
unnamed: J3.23, R12.1
unnamed: J3.33, R15.1
unnamed: J3.36, R16.2
unnamed: J6.8, J7.31, R20.1
unnamed: J6.11, J7.28, R19.1
unnamed: J6.12, J7.27, R18.1
unnamed: J6.13, J7.26, R17.1
unnamed: J7.38, R21.1
unnamed: J9.1, U1.8 (P0_7)
unnamed: C12.1, C13.1, J3.29, JP3.2 (B)
unnamed: R4.2, U1.24 (~RESET)
unnamed: C5.1, U2.3 (C1+)
unnamed: C5.2, U2.2 (C1-)
unnamed: C8.1, R5.2, U3.7 (VREF2), U3.8 (EN)
unnamed: R10.2, U4.4 (PG)
TP1_PWR: C14.1, C15.1, J3.38, J5.8, JP6.2 (C), R14.1
TP2_PWR: C18.1, J8.2, JP7.2 (C), R22.1
TP_3V3: C1.1, C2.1, C3.1, C6.1, J1.3, JP1.1 (A), JP6.3 (B), JP7.1 (A), R1.1, R2.1, R3.1, R4.1, R6.1, R7.1, U1.21 (V_{DD(P)}), U1.23 (V_{DD(I2C-bus)}), U2.1 (PFM), U2.4 (OUTDIS), U2.7 (VIN), U3.2 (VREF1)
TP_5V: C4.1, C7.1, JP6.1 (A), JP7.3 (B), R5.1, R8.1, R9.1, U2.6 (VOUT)
VIN: C9.1, J2.1, J2.2, JP2.1 (A), L1.1, U4.1 (VIN), U4.5 (FB)

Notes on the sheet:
IO Expander
WARNING! check orientation and correct side
Pointing Stick Level Shifter
Keyboard mounting
Control Board Connectors
Pointing Stick Charge Pump
LEDPWR=LEDFNLOCK
Backlight Boost Converter
FFC2 Connectors
FFC1 Connectors
DRV16=KBD_ID
Board mounting
3V3 default to Pointing Stick (FFC2)
Mezzanine Connector
36-pin notched into straight 40-pin
Mounting holes
Warning! Short JP2 only for T430 backlight
tabbed 40-pin
5V default to Pointing Stick (Mezzanine, FFC1)
Port 0: Push-Pull Port 1: Open Collector
Cable guide mounting

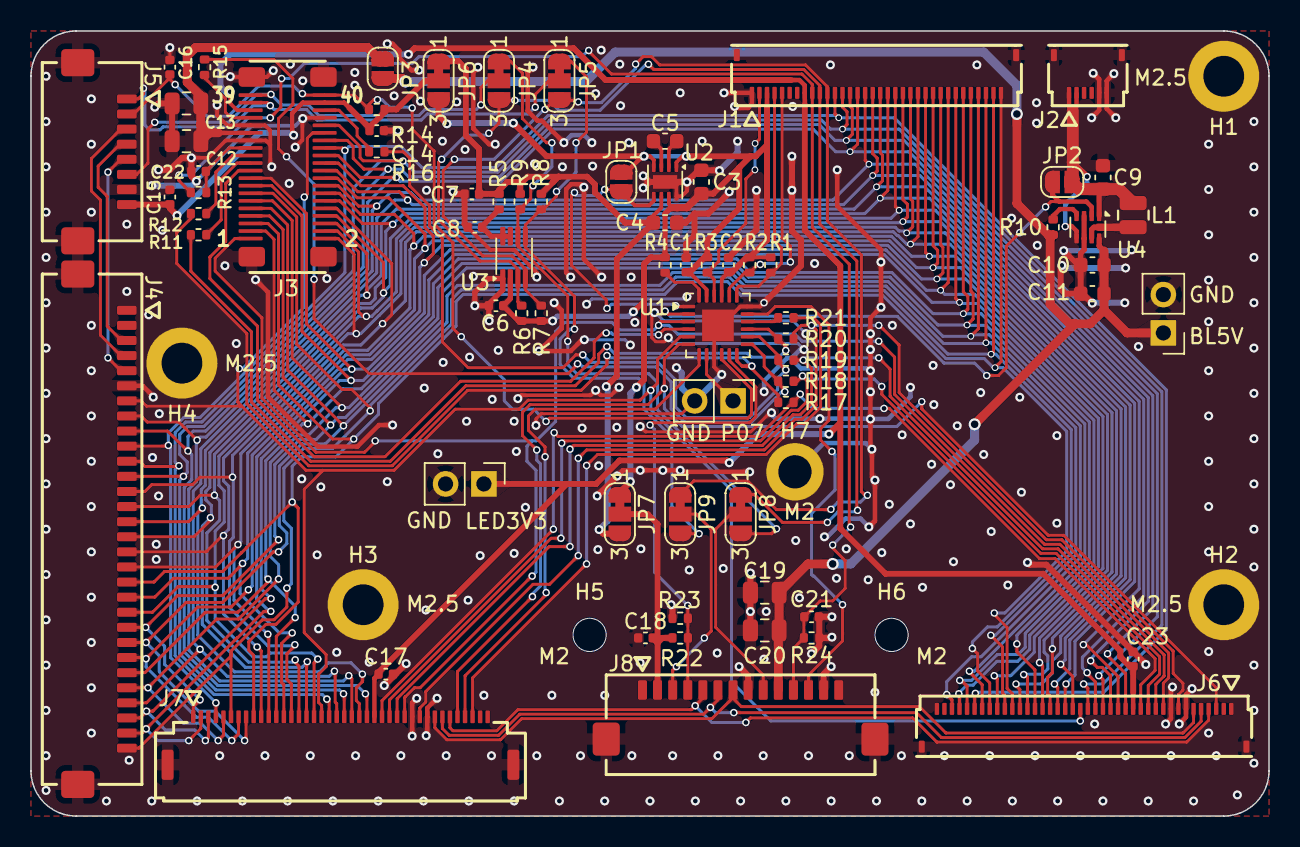
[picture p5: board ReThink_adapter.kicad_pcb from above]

Board: 2 copper layers, 82.0 x 52.0 mm, 79 parts (0 on the bottom side), 82 nets.

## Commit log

2026-09-26 update connectors MPN
2026-09-28 create schematic, upload component libraries
    [ReThink_adapter.kicad_pcb, ReThink_adapter.kicad_sch]
2026-09-29 group connectors on PCB
    [ReThink_adapter.kicad_pcb, ReThink_adapter.kicad_sch]
2026-09-30 added JLCPCB rules
    [ReThink_adapter.kicad_pcb, ReThink_adapter.kicad_sch]
2026-09-30 lock connector placement on adapter PCB
    [ReThink_adapter.kicad_pcb, ReThink_adapter.kicad_sch]
2026-09-30 start routing
    [ReThink_adapter.kicad_pcb, ReThink_adapter.kicad_sch]
2026-10-02 routing mostly done
    [ReThink_adapter.kicad_pcb, ReThink_adapter.kicad_sch]
2026-10-03 finish routing
    [ReThink_adapter.kicad_pcb, ReThink_adapter.kicad_sch]
2026-10-04 added BOM
    [ReThink_adapter.csv, ReThink_adapter.kicad_pcb, ReThink_adapter.kicad_sch]
2026-10-06 add step 3d model, update BOM
    [ReThink_adapter.csv, ReThink_adapter.kicad_pcb, ReThink_adapter.kicad_sch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]
2026-10-09 Added connector guide, start adding keyboard mounting holes
    [ReThink_adapter.kicad_pcb, ReThink_adapter.kicad_sch, connector_guideV1.step]
2026-10-13 add keyboard mounting holes
2026-10-14 update PCB exports PDFs
2026-10-16 add IO expander power selection jumper, charge pump enable pulldown
2026-10-25 add logo to PCB
2026-10-25 ReThink_adapter PCB version 1.0, ordered
2026-10-27 Add logo to readme, fix comments on schematic, add io expander pinout
